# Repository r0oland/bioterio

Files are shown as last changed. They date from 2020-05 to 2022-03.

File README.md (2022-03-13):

# bioterio

Log and display temperature and humidity in your terrarium, aquarium, plant box or if you are totally crazy even your own room...

## Detailed Instructions

See https://www.laserhannes.de/ for details one day...

## Hardware

- D1 Mini
  - ESP8266 uC
  - [SPI and I²C pins for D1 Mini](https://steve.fi/hardware/d1-pins/)
- SH1106
  - 128X64 NONAME display
  - 1,3" OLED Display Weiß SH1106 128x64 SPI 7 Pin Modul Arduino Raspberry Pi
  - <https://www.ebay.de/itm/162572740754>
  - compatible to SSD1305???
- SHT21
  - Humidity and Temperature Sensor IC

## ESP Home

## Licence Infos

[Raleway Font by Google](https://fonts.google.com/specimen/Raleway#glyphs) under the [Open Font License](https://scripts.sil.org/cms/scripts/page.php?site_id=nrsi&id=OFL).

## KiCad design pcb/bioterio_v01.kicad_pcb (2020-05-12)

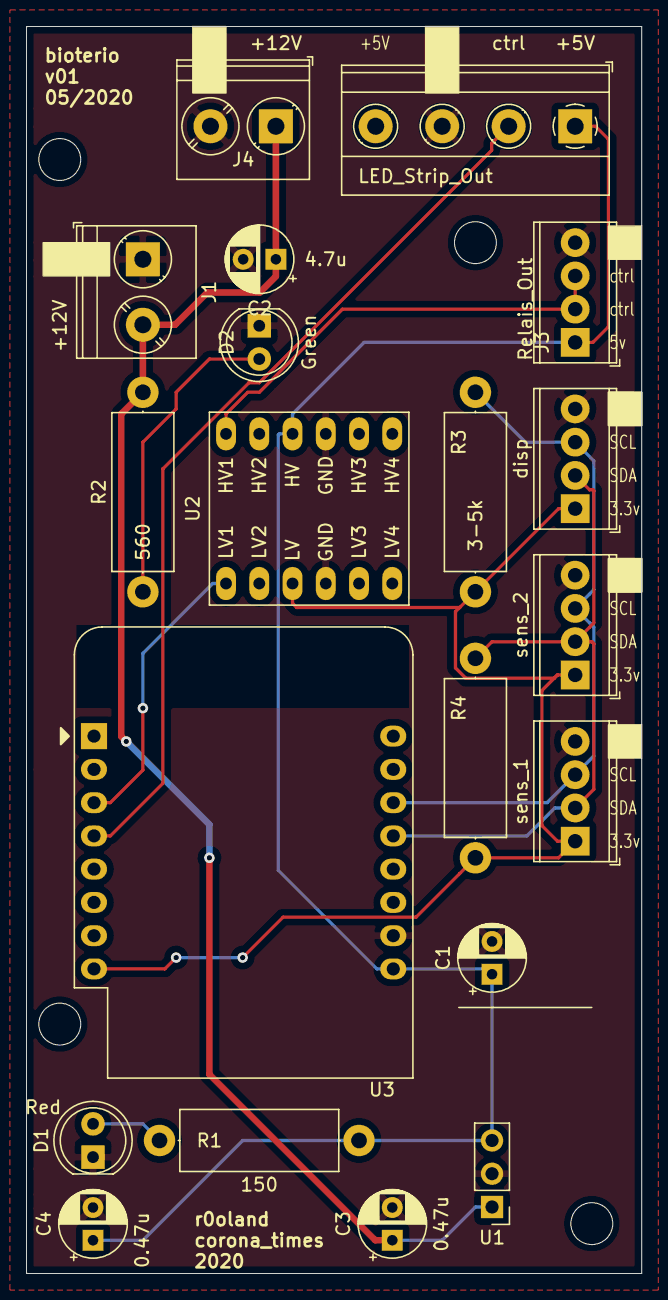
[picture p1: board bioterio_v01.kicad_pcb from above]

Board: 2 copper layers, 47.0 x 95.2 mm, 20 parts (0 on the bottom side), 11 nets.

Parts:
C1, C2: 4.7u; CP_Radial_D5.0mm_P2.50mm
C3, C4: 0.47u; CP_Radial_D5.0mm_P2.50mm
D1: Red; LED_D5.0mm
D2: Green; LED_D5.0mm
J1, J4: +12V; TerminalBlock_Phoenix_PT-1,5-2-5.0-H_1x02_P5.00mm_Horizontal
J3: Relais_Out; TerminalBlock_Phoenix_MPT-0,5-4-2.54_1x04_P2.54mm_Horizontal
R1: 150; R_Axial_DIN0414_L11.9mm_D4.5mm_P15.24mm_Horizontal
R2: 560; R_Axial_DIN0414_L11.9mm_D4.5mm_P15.24mm_Horizontal
R3, R4: 3-5k; R_Axial_DIN0414_L11.9mm_D4.5mm_P15.24mm_Horizontal
U1: L7805; PinHeader_1x03_P2.54mm_Vertical
U2: voltage_conv
U3: WeMos_D1_mini; WEMOS_D1_mini_light
ctrl: LED_Strip_Out; TerminalBlock_Phoenix_MKDS-1,5-4-5.08_1x04_P5.08mm_Horizont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
disp: BME280_2; TerminalBlock_Phoenix_MPT-0,5-4-2.54_1x04_P2.54mm_Horizontal
sens_1: Disp_Out; TerminalBlock_Phoenix_MPT-0,5-4-2.54_1x04_P2.54mm_Horizontal
sens_2: BME280_1; TerminalBlock_Phoenix_MPT-0,5-4-2.54_1x04_P2.54mm_Horizontal

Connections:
+3V3: R3.1, R4.1, U2.3, U3.8, disp.1, sens_1.1, sens_2.1
+5V: C1.1, C4.1, J3.1, R1.2, U1.3, U2.10, U3.9, ctrl.1
+12V: C2.1, C3.1, J1.2, J4.1, R2.2, U1.1
GND: C1.2, C2.2, C3.2, C4.2, D1.1, D2.1, J1.1, J3.4, J4.2, U1.2, U2.4, U2.9, U3.10, ctrl.3, disp.4, sens_1.4, sens_2.4
I²C_SCL: R3.2, U3.14, disp.3, sens_1.3, sens_2.3
I²C_SDA: R4.2, U3.13, disp.2, sens_1.2, sens_2.2
unnamed: D1.2, R1.1
unnamed: D2.2, R2.1
RelaisCtrl3V: U2.1, U3.3
RelaisCtrl5V: J3.2, J3.3, U2.12
led_ctrl_d5: U3.4, ctrl.2

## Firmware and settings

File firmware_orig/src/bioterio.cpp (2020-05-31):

// NOTES
// SDA => D2
// SCL => D1

// always needed
#include <Arduino.h>

// these libs are part of espressif8266 toolbox
#include <ESP8266WiFi.h>
#include "secrets.h"

// for OLED screen
#include <U8g2lib.h> 
U8G2_SH1106_128X64_NONAME_F_SW_I2C u8g2(U8G2_R0,D1,D2); // full buffer size
const uint16_t FRAME_RATE = 3; // frames per second
const uint16_t FRAME_TIME_MILLIS = 1000./FRAME_RATE; // time per frame in milis.
const uint8_t LINE_SPACING = 8; // we can print an new, non-overlapping line

// LED control -----------------------------------------------------------------
#include <FastLED.h> 
// nice to have, also included in fast led
#include "..\lib\every_n_timer\every_n_timer.h" // required for every N seconds thing

FASTLED_USING_NAMESPACE

// defin LED parameters
#define DATA_PIN D5
#define LED_TYPE WS2811
#define COLOR_ORDER GRB
#define NUM_LEDS 10 
#define BRIGHTNESS 25
CRGB leds[NUM_LEDS]; // contains led info, this we set first, the we call led show

// hardware interfacing
#include <Wire.h>
#include <SPI.h>

// adafruit IO and sensors
#include "..\lib\Adafruit IO Arduino\src\AdafruitIO_WiFi.h"
#include <Adafruit_BME280.h>
#include <RunningMedian.h> // used for smoother data...

// init two presure / humid sensors we use
Adafruit_BME280 RightBME; 
Adafruit_BME280 LeftBME;  

const uint8_t RIGHT_ADDRESS = 0x77;
const uint8_t LEFT_ADDDRESS = 0x76;

// setup adafruit stuff
AdafruitIO_WiFi io(IO_USERNAME, IO_KEY, WIFI_SSID, WIFI_PWD);
AdafruitIO_Feed *bigTeraHumid = io.feed("a_big_tera_humid");
AdafruitIO_Feed *smallTeraHumid = io.feed("a_small_tera_humid");
AdafruitIO_Feed *bigTeraTemp = io.feed("a_big_tera_temp");
AdafruitIO_Feed *smallTerraTemp = io.feed("a_small_tera_temp");
AdafruitIO_Feed *minHumidFeed = io.feed("a_min_humid");
AdafruitIO_Feed *maxHumidFeed = io.feed("a_max_humid");

const uint16_t AIO_UPDADTE_TIME = 20; // update AIO every n seconds


// setup time
#include <time.h>
const int8_t TIME_ZONE = -2; // central european time

uint8_t humidRunning = false;
float minRequiredOnHumid = 0;  // keep at least this much humidity
float minRequiredOffHumid = 0; // humid until we reach this value

// calculate running medians for humids and temps
// number of samples = frame rate (== sampling rate) * update interval 
// factor 2 for extra smoothing...
RunningMedian LhsHumid = RunningMedian(AIO_UPDADTE_TIME*FRAME_RATE*2);
RunningMedian LhsTemp  = RunningMedian(AIO_UPDADTE_TIME*FRAME_RATE*2);
RunningMedian RhsHumid = RunningMedian(AIO_UPDADTE_TIME*FRAME_RATE*2);
RunningMedian RhsTemp  = RunningMedian(AIO_UPDADTE_TIME*FRAME_RATE*2);
uint32_t lastMillies = 0;

// function declarations...
void print_values_serial(Adafruit_BME280 *bmeSensor);
void send_aio_values(Adafruit_BME280 *insideSensor, Adafruit_BME280 *outsideSensor);
void updateMinHumid(AdafruitIO_Data *data);
void updateMaxHumid(AdafruitIO_Data *data);
void setup_leds();
void set_led_status(uint8_t status);
void pulse_leds(uint8_t nPulses, uint8_t pulseSpeed);

// %%%%%%%%%%%%%%%%%%%%%%%%%%%%%%%%%%%%%%%%%%%%%%%%%%%%%%%%%%%%%%%%%%%%%%%%%%%%%
void setup()
{
  uint8_t thisLine = 1;
  // setup screen, say hello
  u8g2.begin(); 
  u8g2.clearBuffer();
  u8g2.setFont(u8g2_font_5x8_mr); 
  u8g2.setCursor(0,LINE_SPACING*thisLine++); // start at first line, then increment
  u8g2.print("bioterio 0.2");
  u8g2.setCursor(0,LINE_SPACING*8); // print signature in last line
  u8g2.print("Laser Hannes 2020");
  u8g2.sendBuffer();
  delay(250);

  Serial.begin(921600);
  while (!Serial)
    ; // wait for serial monitor to open

  // setting up leds ===========================================================
  u8g2.setCursor(0,LINE_SPACING*thisLine++); 
  u8g2.print("Setting up leds...");
  u8g2.sendBuffer();
  setup_leds();
  u8g2.print("done!");
  set_led_status(1); // working

  // setting up the sensors ====================================================
  u8g2.setCursor(0,LINE_SPACING*thisLine++); 
  u8g2.print("Sensor searching...");
  u8g2.sendBuffer();

  while (!RightBME.begin(RIGHT_ADDRESS, &Wire))
  {
    delay(2500);
  }
  while (!LeftBME.begin(LEFT_ADDDRESS, &Wire))
  {
    delay(2500);
  }
  u8g2.print("done!");

  u8g2.setCursor(0,LINE_SPACING*thisLine++); 
  u8g2.print("Sensor setup...");
  u8g2.sendBuffer();
  // see https://cdn-shop.adafruit.com/datasheets/BST-BME280_DS001-10.pdf 
  // for datasheet of sensor
  RightBME.setSampling(Adafruit_BME280::MODE_NORMAL,
                Adafruit_BME280::SAMPLING_X16,  // temperature
                Adafruit_BME280::SAMPLING_NONE, // pressure
                Adafruit_BME280::SAMPLING_X16,  // humidity
                Adafruit_BME280::FILTER_OFF,
                Adafruit_BME280::STANDBY_MS_0_5);

  LeftBME.setSampling(Adafruit_BME280::MODE_NORMAL,
                  Adafruit_BME280::SAMPLING_X16,  // temperature
                  Adafruit_BME280::SAMPLING_NONE, // pressure
                  Adafruit_BME280::SAMPLING_X16,  // humidity
                  Adafruit_BME280::FILTER_OFF,
                  Adafruit_BME280::STANDBY_MS_0_5);
  // suggested rate is 1Hz (1s)
  u8g2.print("done!");

  // connect to io.adafruit.com ================================================
  u8g2.setCursor(0,LINE_SPACING*thisLine++); 
  u8g2.print("Ada connecting");
  u8g2.sendBuffer();

  io.connect(); // WiFi.begin(WIFI_SSID, WIFI_PWD) called here!
  minHumidFeed->onMessage(updateMinHumid);
  maxHumidFeed->onMessage(updateMaxHumid);

  // wait for a connection
  while (io.status() < AIO_CONNECTED)
  {
    u8g2.print(".");
    u8g2.sendBuffer();
    delay(500);
  }
  // we are connected
  u8g2.setCursor(0,LINE_SPACING*thisLine++); 
  u8g2.print(io.statusText());
  u8g2.sendBuffer();
  send_aio_values(&RightBME, &LeftBME);
  // get latest minMax values for humidity from AIO 
  minHumidFeed->get();
  maxHumidFeed->get();

  // connect to time server
  u8g2.setCursor(0,LINE_SPACING*thisLine++); 
  u8g2.print("Waiting for time");
  configTime(TIME_ZONE*3600, 0 , "pool.ntp.org", "time.nist.gov"); // 
  while (!time(nullptr)) {
    u8g2.print(".");
    u8g2.sendBuffer();
    delay(500);
  }

  // setup my own IO pins
  pinMode(D0, OUTPUT); // relais for fan and humidifier
  digitalWrite(D0, 1); // relais is active low
}

// %%%%%%%%%%%%%%%%%%%%%%%%%%%%%%%%%%%%%%%%%%%%%%%%%%%%%%%%%%%%%%%%%%%%%%%%%%%%%
void loop()
{
  io.run(); // required for all sketches.

  EVERY_N_MILLISECONDS(FRAME_TIME_MILLIS) // update display
  {
    // float currentLhsHumid = LeftBME.readHumidity();
    // float currentLhsTemp = LeftBME.readTemperature();
    LhsHumid.add(LeftBME.readHumidity());
    LhsTemp.add(LeftBME.readTemperature());
    RhsHumid.add(RightBME.readHumidity());
    RhsTemp.add(RightBME.readTemperature());

    uint8_t thisLine = 1;
    u8g2.clearBuffer();
    u8g2.setCursor(0,LINE_SPACING*thisLine++); 
    u8g2.print("      lhs  rhs  min max");

    u8g2.setCursor(0,LINE_SPACING*thisLine++); 
    u8g2.print(" Temp ");
    u8g2.print(LhsTemp.getMedian(), 1);
    u8g2.print(" ");
    u8g2.print(RhsTemp.getMedian(), 1);
    u8g2.print(" ");

    u8g2.setCursor(0,LINE_SPACING*thisLine++); 
    u8g2.print("Humid ");
    u8g2.print(LhsHumid.getMedian(), 1);
    u8g2.print(" ");
    u8g2.print(RhsHumid.getMedian(), 1);
    u8g2.print(" ");
    u8g2.print(minRequiredOnHumid, 0);
    u8g2.print(" ");
    u8g2.print(minRequiredOffHumid, 0);

    u8g2.setCursor(0,LINE_SPACING*thisLine++); 
    uint32_t thisTime = millis();
    uint32_t timeDiff = thisTime - lastMillies;
    lastMillies = millis();
    u8g2.print(timeDiff);

    thisLine++; // skip one line
    u8g2.setCursor(0,LINE_SPACING*thisLine++); 
    if (humidRunning)
      u8g2.print("Humidifier is ON");
    else
      u8g2.print("Humidifier is OFF");

    time_t now = time(nullptr);
    u8g2.setCursor(0,LINE_SPACING*8); 
    u8g2.print(ctime(&now)); 
    u8g2.sendBuffer();
  }

  EVERY_N_SECONDS(20) // send AIO values and update AIO status
  {
    // TODO check for reasonable values before sending them...
    send_aio_values(&RightBME, &LeftBME);
  }

  EVERY_N_SECONDS(10) // control humidifier
  {
    float rightHumid = RightBME.readHumidity();
    float leftHumid = LeftBME.readHumidity();

    // if one is to low, turn on humidifier
    bool leftHumidToLow = (leftHumid < minRequiredOnHumid);
    bool rightHumidToLow = (rightHumid < minRequiredOnHumid);
    bool humidToLow = rightHumidToLow || leftHumidToLow;

    // if both are high enough, turn off humidifier
    bool leftHumidReached = (leftHumid > minRequiredOffHumid);
    bool rightHumidReached = (rightHumid > minRequiredOffHumid);
    bool humidReached = leftHumidReached && rightHumidReached;
    if (humidToLow && !humidRunning)
    {
      humidRunning = true;
      digitalWrite(D0, 0);
    }
    else if (humidRunning && humidReached)
    {
      humidRunning = false;
      digitalWrite(D0, 1);
    }
  }
}

void print_values_serial(Adafruit_BME280 *bmeSensor)
{
  Serial.println("-------------------------------------------");
  Serial.print("Temperature = ");
  Serial.print(bmeSensor->readTemperature());
  Serial.println(" *C");

  Serial.print("Pressure = ");
  Serial.print(bmeSensor->readPressure() / 100.0F);
  Serial.println(" hPa");

  Serial.print("Humidity = ");
  Serial.print(bmeSensor->readHumidity());
  Serial.println(" %");

  Serial.println("-------------------------------------------");
}

void send_aio_values(Adafruit_BME280 *insideSensor, Adafruit_BME280 *outsideSensor)
{
  bigTeraHumid->save(insideSensor->readHumidity());
  bigTeraTemp->save(insideSensor->readTemperature());

  smallTeraHumid->save(outsideSensor->readHumidity());
  smallTerraTemp->save(outsideSensor->readTemperature());
}

void updateMinHumid(AdafruitIO_Data *data)
{
  minRequiredOnHumid = data->toFloat();
  Serial.print("New minimum Humidity: ");
  Serial.println(minRequiredOnHumid);
}

void updateMaxHumid(AdafruitIO_Data *data)
{
  minRequiredOffHumid = data->toFloat();
  Serial.print("New maximum Humidity: ");
  Serial.println(minRequiredOffHumid);
}

void setup_leds()
{
  // tell FastLED about the LED strip configuration
  FastLED.addLeds<LED_TYPE, DATA_PIN, COLOR_ORDER>(leds, NUM_LEDS).setCorrection(TypicalLEDStrip);

  // set master brightness control
  FastLED.setBrightness(BRIGHTNESS);

  FastLED.clear();
  FastLED.show();
  for (int led = 0; led < NUM_LEDS; led++)
  {
    leds[led] = CRGB::White;
    delay(100);
    FastLED.show();
  }
  delay(100);
  pulse_leds(3, 5);
  FastLED.clear();
  FastLED.show();
}

void pulse_leds(uint8_t nPulses, uint8_t pulseSpeed)
{
  uint8_t ledFade = 255;      // start with LEDs off
  int8_t additionalFade = -5; // start with LEDs getting brighter
  uint8_t iPulse = 0;

  while (iPulse < nPulses)
  {
    for (uint8_t iLed = 0; iLed < NUM_LEDS; iLed++)
    {
      leds[iLed].setRGB(255, 255, 255);
      leds[iLed].fadeLightBy(ledFade);
    }
    FastLED.show();
    ledFade = ledFade + additionalFade;
    // reverse the direction of the fading at the ends of the fade:
    if (ledFade == 0 || ledFade == 255)
      additionalFade = -additionalFade;
    if (ledFade == 255)
      iPulse++;
    delay(pulseSpeed); // This delay sets speed of the fade. I usually do from 5-75 but you can always go higher.
  }
}

void set_led_status(uint8_t status)
{
  // first led in array displays overall status
  // (0 = all good, 1 = working, 2 = error)
  switch (status)
  {
  case 0:
    leds[0].setRGB(0, 255, 0); // all good = green
    FastLED.show();
    break;
  case 1:
    leds[0].setRGB(200, 165, 0); // working == orange
    FastLED.show();
    break;
  case 2:
    leds[0].setRGB(255, 0, 0); // error == red
    FastLED.show();
    break;

  default:
    leds[0].setRGB(255, 0, 0);
    FastLED.show();
    break;
  }
}

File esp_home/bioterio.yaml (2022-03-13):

esphome:
  name: terra

esp8266:
  board: d1_mini

# Enable logging
logger:
  level: DEBUG

# Enable Home Assistant API
api:
  password: ""

ota:
  password: ""

wifi:
  ssid: "Kassiopeia"
  password: "SternbilddesNordhimmels"

  # Enable fallback hotspot (captive portal) in case wifi connection fails
  # ap:
  #   ssid: "Terra Fallback Hotspot"
  #   password: "Ra683jvKEaCg"

# captive_portal:

i2c:
  # use default HW pins 
  # sda: 21 
  # scl: 22
  scan: false

# sensors =====================================================

sensor:
  - platform: htu21d
    temperature:
      name: "TerraTemp"
      id: TerraTemp
      filters:
        - sliding_window_moving_average:
            window_size: 10
            send_every: 60
    humidity:
      name: "TerraHumid"
      id: TerraHumid
      filters:
        - sliding_window_moving_average:
            window_size: 10
            send_every: 60
    update_interval: 10s


# display and font stuff =====================================================
font:
  - file: "fonts/Raleway-Medium.ttf"
    id: ral_med_15
    size: 15
  - file: "fonts/Raleway-Medium.ttf"
    id: ral_med_20
    size: 20

graph:
  # Show bare-minimum auto-ranged graph
  - id: tempGraph
    sensor: TerraTemp
    duration: 6h
    width: 60
    height: 40
    x_grid: 2h
    border: true
  - id: humidGraph
    sensor: TerraHumid
    duration: 6h
    width: 60
    height: 40
    x_grid: 2h
    border: true

display:
  - platform: ssd1306_i2c
    id: the_display
    model: "SH1106 128x64"
    address: 0x3C # default is 0x3C
    pages:
    - id: page1
      lambda: |-
        it.printf(0, 0, id(ral_med_20), "%.1f C", id(TerraTemp).raw_state);
        it.printf(64, 0, id(ral_med_20), "%.1f %%", id(TerraHumid).raw_state);
        it.graph(0, 24, id(tempGraph));
        it.graph(64, 24, id(humidGraph));

# For example cycle through pages on a timer
# interval:
#   - interval: 5s
#     then:
#       - display.page.show_next: the_display
#       - component.update: the_display

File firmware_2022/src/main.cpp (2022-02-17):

#include <Arduino.h>
#include <ESP8266WiFi.h>
#include <U8g2lib.h>

#include "SHT2x.h"
#include "secrets.h"

char lineBuffer[20];

U8G2_SH1106_128X64_NONAME_F_HW_I2C u8g2(U8G2_R0);
SHT2x sht;

void setup(void) {

  Serial.begin(115200);

  Serial.print("u8g2\n");
  u8g2.begin();
  u8g2.enableUTF8Print();

  Serial.print("sht\n");
  sht.begin();
  sht.getStatus();

  // u8g2.setFont(u8g2_font_streamline_internet_network_t);
  while (!sht.isConnected()) {
    Serial.print("...");
    delay(250);
  }
  Serial.print("\n");
}

float temp = 0.00;
float humid = 0.00;

void loop(void) {

  if (sht.isConnected()) {
    sht.read();
    sht.getError();
    sht.getStatus();
    humid = sht.getHumidity();
    temp = sht.getTemperature();
    Serial.print("humid ");
    Serial.print(humid);
    Serial.print(" temp ");
    Serial.print(temp);
    Serial.print("\n");
  } else {
    temp = -99.9;
    humid = -99.9;
  }

  u8g2.clearBuffer();
  u8g2.setFont(u8g2_font_smart_patrol_nbp_tf);
  
  snprintf(lineBuffer, 20, "Humid: %03.2f %%", humid);
  u8g2.drawStr(0, 20, lineBuffer);

  snprintf(lineBuffer, 20, " Temp: %03.2f %%", temp);
  u8g2.drawStr(0, 40, lineBuffer);

  u8g2.setFont(u8g2_font_streamline_internet_network_t);
  u8g2.drawGlyph(100, 64, 0x31);  // WIFI not working
  // u8g2.setFontMode(1); /* activate transparent font mode */
  // u8g2.setDrawColor(0);
  
  u8g2.sendBuffer();


  delay(1000);
}

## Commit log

2020-05-02 add firmware and pcb folders, move pcb files here as well
    [bioterio_v01.kicad_pcb, bioterio_v01.sch]
2020-05-10 adding full schematic and PCB
    [bioterio_v01.sch]
2020-05-12 getting gerber and such
    [bioterio_v01-B_Cu.gbr, bioterio_v01-B_Mask.gbr, bioterio_v01-B_Paste.gbr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]
2020-05-31 updated pcb, slight firmware updates
    [bioterio_v01-B_Cu.gbr, bioterio_v01-B_Mask.gbr, bioterio_v01-B_Paste.gbr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]
